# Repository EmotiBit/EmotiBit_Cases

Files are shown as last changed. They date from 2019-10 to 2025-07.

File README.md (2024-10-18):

## EmotiBit Cases

| EmotiBit Case | Preview | EmotiBit<br>Compatibility | Feather<br>Compatibility |
| --- | --- | --- | --- |
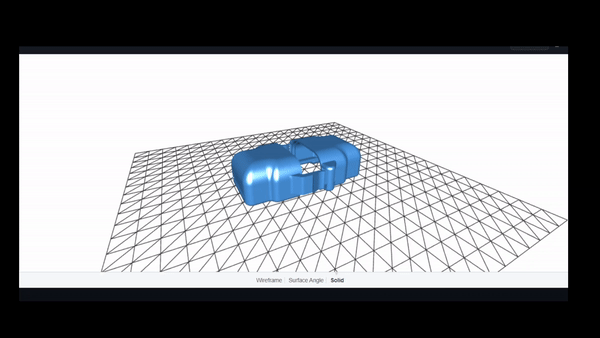
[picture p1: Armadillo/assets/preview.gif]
| [SwissArmyCase](./SwissArmyCase/) |  | <table><tr><th>EmotiBit<br>Version</th><th>Fit?</th></tr><tr><td>V01</td><td>Y</td></tr><tr><td>V02</td><td>Y</td></tr><tr><td>V03</td><td>Y</td></tr><tr><td>V04+</td><td>Y</td></tr></table> | <table><tr><th>Feather<br>Version</th><th>Fit?</th></tr><tr><td><a href=https://www.adafruit.com/product/2598>M0 WiFi<br>Regular Header</a></td><td>Y</td></tr><tr><td><a href=https://www.adafruit.com/product/3044>M0 WiFi<br>Stacking Header</a></td><td>Y</td></tr><tr><td><a href=https://www.adafruit.com/product/3591>HUZZAH32 <br>Regular Header</a></td><td>Y</td></tr><tr><td><a href=https://www.adafruit.com/product/3619>HUZZAH32 <br>Stacking Header</a></td><td>Y</td></tr></table> |
| [Armadillo](./Armadillo/) |  | <table><tr><th>EmotiBit<br>Version</th><th>Fit?</th></tr><tr><td>V01</td><td>Y</td></tr><tr><td>V02</td><td>Y</td></tr><tr><td>V03</td><td>Y</td></tr><tr><td>V04+</td><td>Y?</td></tr></table> | <table><tr><th>Feather<br>Version</th><th>Fit?</th></tr><tr><td><a href=https://www.adafruit.com/product/2598>M0 WiFi<br>Regular Header</a></td><td>Y</td></tr><tr><td><a href=https://www.adafruit.com/product/3044>M0 WiFi<br>Stacking Header</a></td><td>N</td></tr></table> |
| [NinjaCase](./NinjaCase/) |  | <table><tr><th>EmotiBit<br>Version</th><th>Fit?</th></tr><tr><td>V01</td><td>Y?</td></tr><tr><td>V02</td><td>Y?</td></tr><tr><td>V03</td><td>Y?</td></tr><tr><td>V04+</td><td>Y</td></tr></table> | <table><tr><th>Feather<br>Version</th><th>Fit?</th></tr><tr><td><a href=https://www.adafruit.com/product/2598>M0 WiFi<br>Regular Header</a></td><td>Y*</td></tr><tr><td><a href=https://www.adafruit.com/product/3044>M0 WiFi<br>Stacking Header</a></td><td>N</td></tr></table> |
## Want to Contribute to the EmotiBit Cases Repository?
See [CONTRIBUTING.md](./CONTRIBUTING.md)

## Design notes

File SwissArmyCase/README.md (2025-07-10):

## Description
- The case has been designed keeping in mind the design requirements for EmotiBit V4+ and extending compatibility with Adafruit Feather with stacking headers.
- The slider has been designed to provide easy access to toggle the hibernate (HIB) switch (available on EmotiBit V4+).

## Preview

### Case



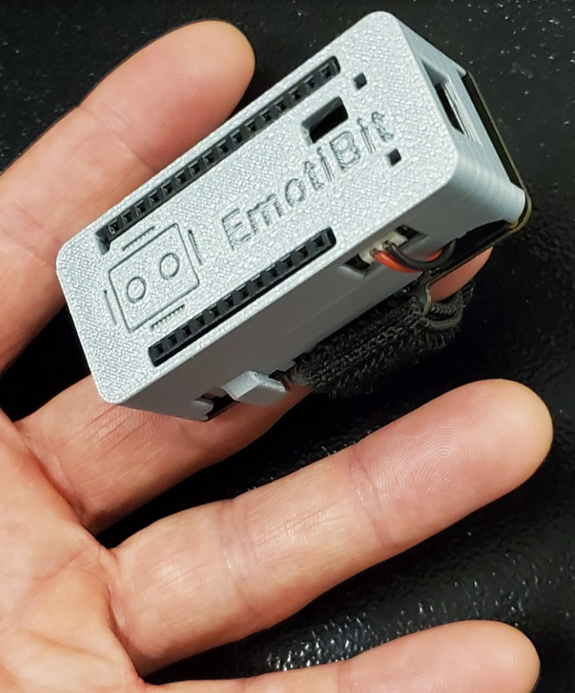
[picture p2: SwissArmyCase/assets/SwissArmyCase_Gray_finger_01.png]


### Slider
- The slider when correctly positioned inside the case, provides an easy and convinient way to toggle the hibernate (HIB)
switch. 
- The hibernate (HIB) switch can be toggled by by pushing the slider in from either direction. 

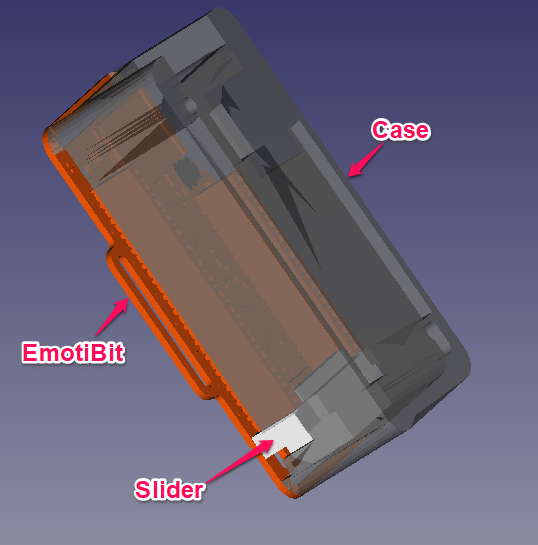
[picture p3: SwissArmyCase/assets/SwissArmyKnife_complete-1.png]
 

[ToDo: Add updated image]

## EmotiBit Compatibility
<!--- This table is written in minified html to permit scraping into a sub-table in the root EmotiBit_Cases/readme.md -->
<table><tr><th>EmotiBit<br>Version</th><th>Fit?</th></tr><tr><td>V01</td><td>Y</td></tr><tr><td>V02</td><td>Y</td></tr><tr><td>V03</td><td>Y</td></tr><tr><td>V04+</td><td>Y</td></tr></table>

## Feather Compatibility
<!--- This table is written in minified html to permit scraping into a sub-table in the root EmotiBit_Cases/readme.md -->
<table><tr><th>Feather<br>Version</th><th>Fit?</th></tr><tr><td><a href=https://www.adafruit.com/product/2598>M0 WiFi<br>Regular Header</a></td><td>Y</td></tr><tr><td><a href=https://www.adafruit.com/product/3044>M0 WiFi<br>Stacking Header</a></td><td>Y</td></tr><tr><td><a href=https://www.adafruit.com/product/3591>HUZZAH32 <br>Regular Header</a></td><td>Y</td></tr><tr><td><a href=https://www.adafruit.com/product/3619>HUZZAH32 <br>Stacking Header</a></td><td>Y</td></tr></table>

## Hardware Modifications
None required.

## 3D Printing
| Works? | Vendor/Printer | Material | Notes |
| :----: | --- | --- | --- |
| Y | [xometry](https://www.xometry.com/) | Selective Laser Sintering (SLS) Nylon 12 | Process: 3D Printing Technology: Selective Laser Sintering (SLS) Material: Nylon 12, Color: Black-Dyed Finish: Standard |

## Additional Hardware
None

## Assembly
- Stack the EmotiBit as demonstrated in the [documentation](https://github.com/EmotiBit/EmotiBit_Docs/blob/master/Getting_Started.md#stack-your-emotibit), but don't plug the battery into the Feather just yet.
- Place the slider between the EmotiBit and Feather such that the bottom notch on the slider fits over the hibernate (HIB) switch on EmotiBit.
- Fit the case over assembled EmotiBit+Feather (with the slider now sandwiched between the EmotiBit and Feather).
  - You will notice that the slider stands flush with the slots on the case.
  - Gently bring the case down and fasten the clips over the EmotiBit.
- Plug in the battery.

[ToDo: add images demonstrating assembly]

## Feature Accessibility
| Feature | Accessible? |
| --- | :----: |
| SD card | Y |
| EmotiBit Button | Y |
| USB connector | Y |
| EmotiBit LEDs visible | Y |
| Feather LEDs visible | Y |
| Short-edge EmotiBit strap slots | Y |
| Long-edge EmotiBit strap slots  | Y |
| Hibernate switch (with slider) | Y |
| Battery connector | Y |
| Battery removal/replacement | Case must be partially removed |
| Feather reset button | Requires spudger |
| Feather stacking header pins | Y |

## Known Limitations
None

## Credits
Designed by the EmotiBit team

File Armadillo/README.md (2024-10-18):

## Description
This case was designed for snowboarders to wear EmotiBit while performing tricks in a halfpipe. 

## Preview


## EmotiBit Compatibility
<!--- This table is written in minified html to permit scraping into a sub-table in the root EmotiBit_Cases/readme.md -->
<table><tr><th>EmotiBit<br>Version</th><th>Fit?</th></tr><tr><td>V01</td><td>Y</td></tr><tr><td>V02</td><td>Y</td></tr><tr><td>V03</td><td>Y</td></tr><tr><td>V04+</td><td>Y?</td></tr></table>

### EmotiBit Compatibility Notes
- EmotiBit V04/V05 just barely fits length-wise into this case with Shapeways PVP print. This case may not fit V04/V05 with other printers/plastic.

## Feather Compatibility
<!--- This table is written in minified html to permit scraping into a sub-table in the root EmotiBit_Cases/readme.md -->
<table><tr><th>Feather<br>Version</th><th>Fit?</th></tr><tr><td><a href=https://www.adafruit.com/product/2598>M0 WiFi<br>Regular Header</a></td><td>Y</td></tr><tr><td><a href=https://www.adafruit.com/product/3044>M0 WiFi<br>Stacking Header</a></td><td>N</td></tr></table>

## Hardware Modifications
None required.

## 3D Printing
| Works? | Vendor/Printer | Material | Notes |
| :----: | --- | --- | --- |
| Y | [shapeways](https://www.shapeways.com/) | Processed Versatile Plastic | Robust case for extreme conditions. |
| Y? | [shapeways](https://www.shapeways.com/) | Dark Gray PA12 Glass Beads | Somewhat fragile. Clips can break if not careful. |

## Additional Hardware
None

## Feature Accessibility
| Feature | Accessible? |
| --- | :----: |
| SD card | Case must be partially removed |
| EmotiBit Button | Case must be partially removed |
| USB connector | Case must be partially removed |
| EmotiBit LEDs visible | LEDs are somewhat visible through case material |
| Feather LEDs visible | LEDs are somewhat visible through case material |
| Short-edge EmotiBit strap slots | Y |
| Long-edge EmotiBit strap slots  | N |
| Hibernate switch | Case must be partially removed |
| Battery connector | Case must be partially removed |
| Battery removal/replacement | Case must be partially removed |
| Feather reset button | Case must be partially removed |
| Feather stacking header pins | N/A |

## Known Limitations
This case will work ONLY when using with a non-stacking Adafruit Feather (e.g. https://www.adafruit.com/product/2598), such as those shipped with EmotiBit Beta Units.



With a stacking-header Adafruit Feather (e.g. https://www.adafruit.com/product/3044) that is shipping with Kickstarter orders and preorders on http://shop.emotibit.com/ a slightly taller case design must be utilized.



## Credits
Designed by the Paquette Lab at the Université du Québec à Chicoutimi (UQAC)

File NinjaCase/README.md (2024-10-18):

## Description
This case requires removing the battery connector. It exposes only the side velcro band slots. Designed to print in flexible filament.

## Preview


## EmotiBit Compatibility
<!--- This table is written in minified html to permit scraping into a sub-table in the root EmotiBit_Cases/readme.md -->
<table><tr><th>EmotiBit<br>Version</th><th>Fit?</th></tr><tr><td>V01</td><td>Y?</td></tr><tr><td>V02</td><td>Y?</td></tr><tr><td>V03</td><td>Y?</td></tr><tr><td>V04+</td><td>Y</td></tr></table>

## Feather Compatibility
<!--- This table is written in minified html to permit scraping into a sub-table in the root EmotiBit_Cases/readme.md -->
<table><tr><th>Feather<br>Version</th><th>Fit?</th></tr><tr><td><a href=https://www.adafruit.com/product/2598>M0 WiFi<br>Regular Header</a></td><td>Y*</td></tr><tr><td><a href=https://www.adafruit.com/product/3044>M0 WiFi<br>Stacking Header</a></td><td>N</td></tr></table>

## Hardware Modifications
You must de-solder the battery connector on the Feather, and hard solder the battery wires to the Feather battery connector pads.

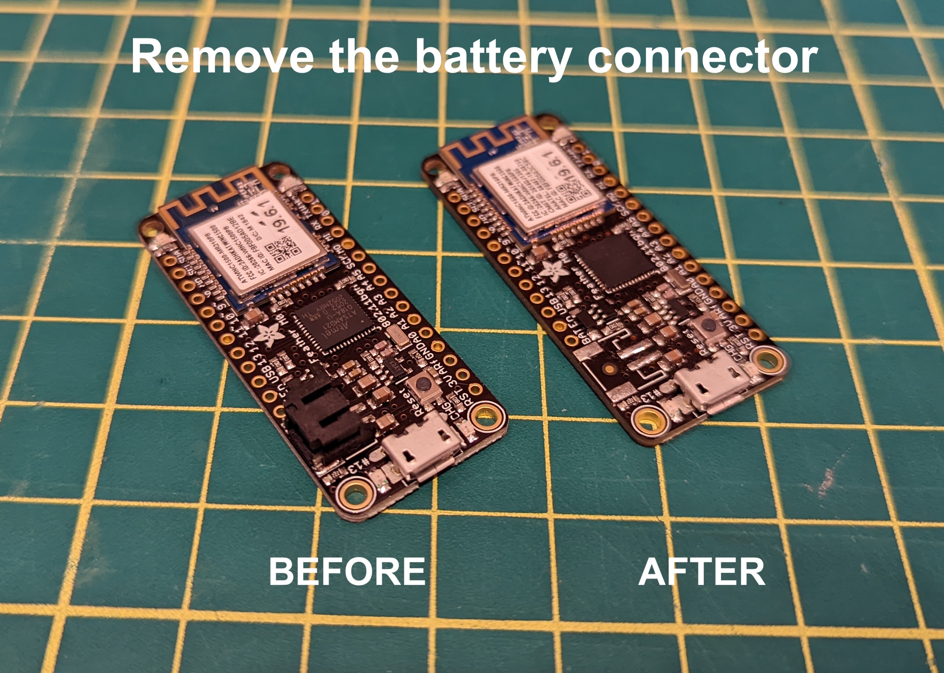
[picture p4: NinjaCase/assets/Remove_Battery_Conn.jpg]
Feather Battery connector


In order to protect the battery wires, it's best to route them through the Feather Mount Hole right next to the battery solder pads.

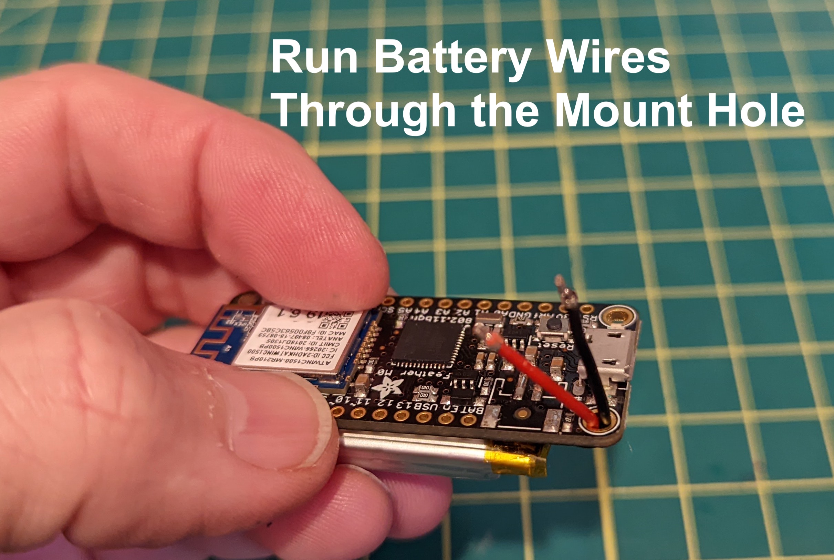
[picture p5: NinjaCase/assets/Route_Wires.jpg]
Route Wires


The black wire (GND) solders to the skinny pad closer to the USB port.
Red wire goes on the skinny pad further from the USB port.

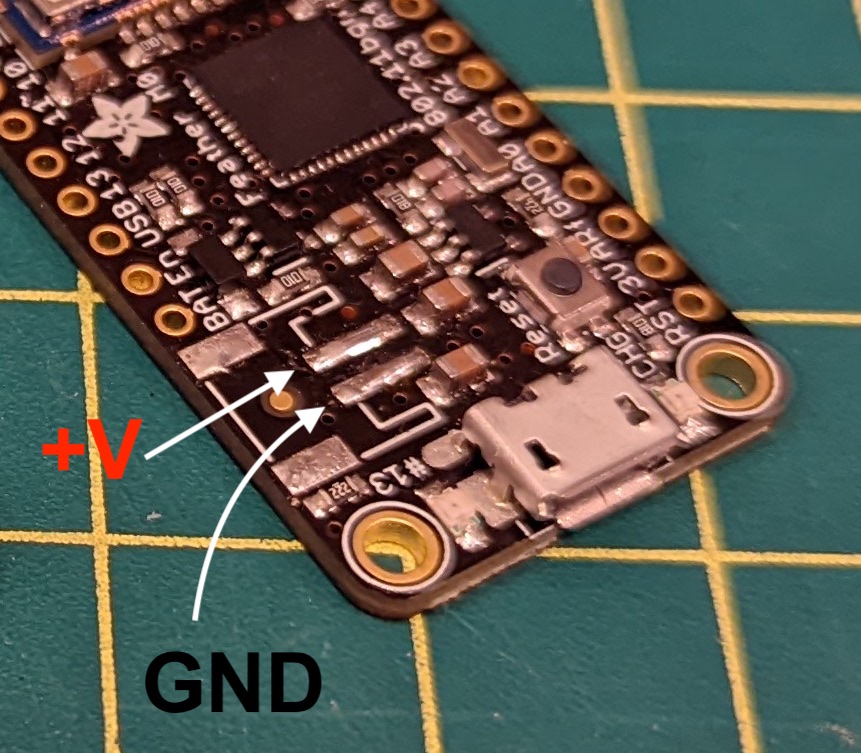
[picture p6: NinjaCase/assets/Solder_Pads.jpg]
Solder Pads


Install the Feather + Emotibit into the case by first sliding in the USB end. Then stretch the case around the opposite end of the Feather + Emotibit assembly. It's kind of like putting on a bike tire. Best to use a spudger or other plastic tool to stretch against the PCBs. 

## 3D Printing
| Works? | Vendor/Printer | Material | Notes |
| :----: | --- | --- | --- |
| Y | TAZ Mini 2 | NinjaTek Ninja Flex filament | 20% Infill. With Supports. Standard Resolution. |

## Additional Hardware
None

## Feature Accessibility
| Feature | Accessible? |
| --- | :----: |
| SD card | Y |
| EmotiBit Button | Y |
| USB connector | Y |
| EmotiBit LEDs visible | Y |
| Feather LEDs visible | N |
| Short-edge EmotiBit strap slots | N |
| Long-edge EmotiBit "side" strap slots  | Y |
| Hibernate switch | N |
| Battery connector | Removed |
| Battery removal/replacement | Soldered |
| Feather reset button | With paperclip |
| Feather stacking header pins | N |

## Known Limitations
Some caution should be exercised when inserting/removing EmotiBit. It's a tight fit and it can damage the EmotiBit strap slots if you aren't careful.

## Credits
Designed by the Joel Murphy @biomurph

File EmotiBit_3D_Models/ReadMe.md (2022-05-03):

3D models of different EmotiBit versions can be found in this directory.

After removing the SD card, the version information for each EmotiBit can be found written in white silkscreen lettering on the PCB.

[ToDo: Add image]

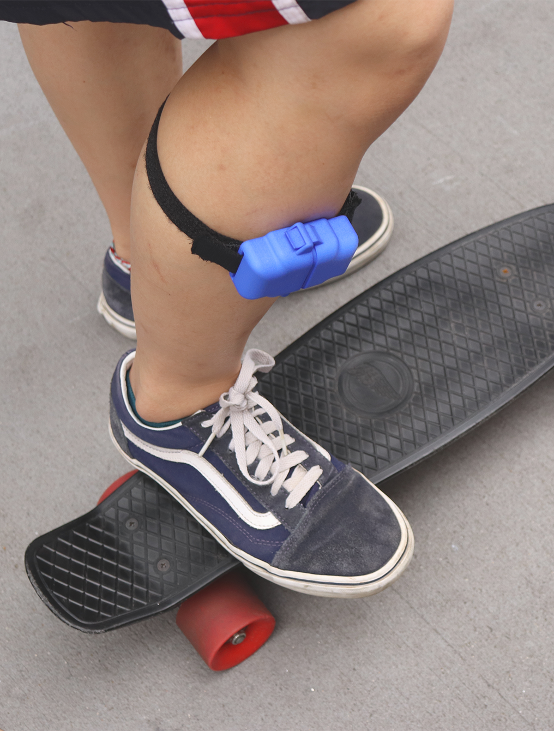
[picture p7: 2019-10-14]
Armadillo/skateboard5.png

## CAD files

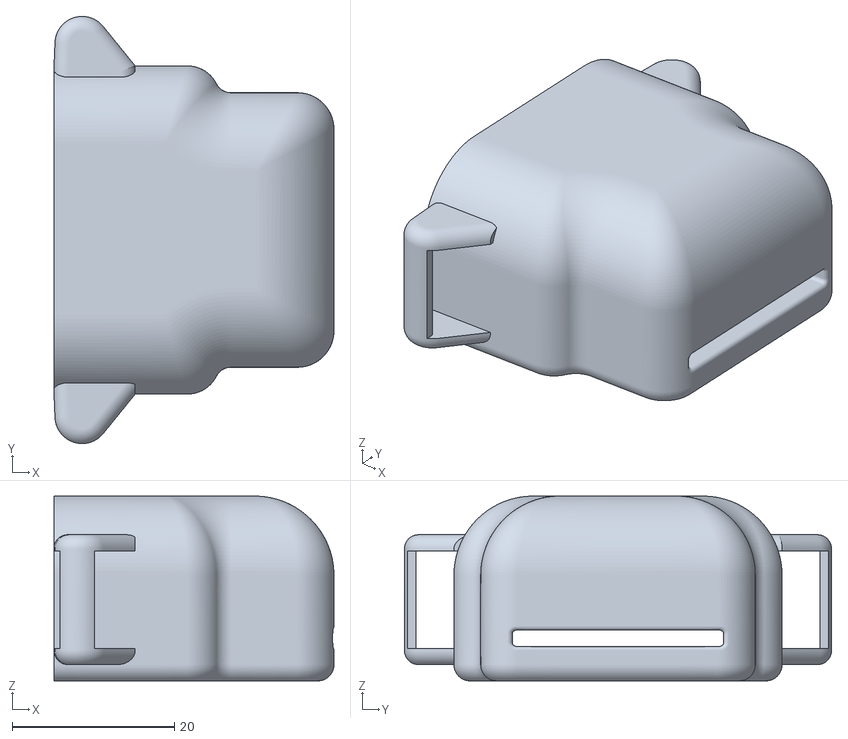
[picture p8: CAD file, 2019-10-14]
Armadillo/Armadillo-part1.stl
34.5 x 52.6 x 22.8

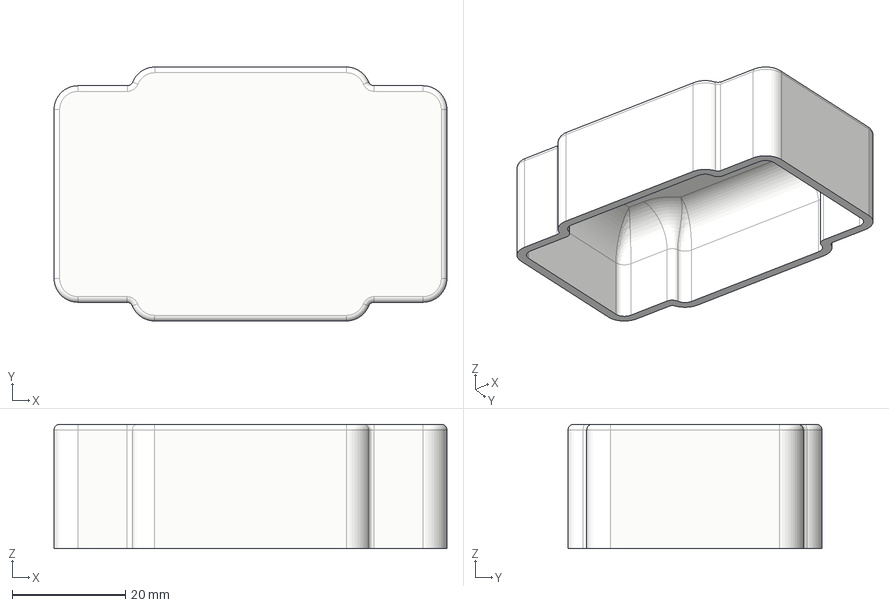
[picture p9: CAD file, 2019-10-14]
Armadillo/STEP files/Emotibit_moule.step
69.5 x 44.9 x 22.0 mm

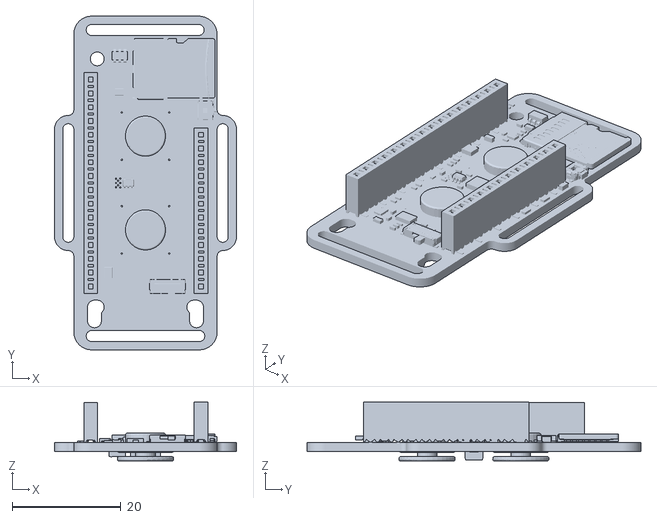
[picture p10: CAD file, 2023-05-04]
EmotiBit_3D_Models/V06/EmotiBit_V06.stl
33.5 x 61.5 x 10.9

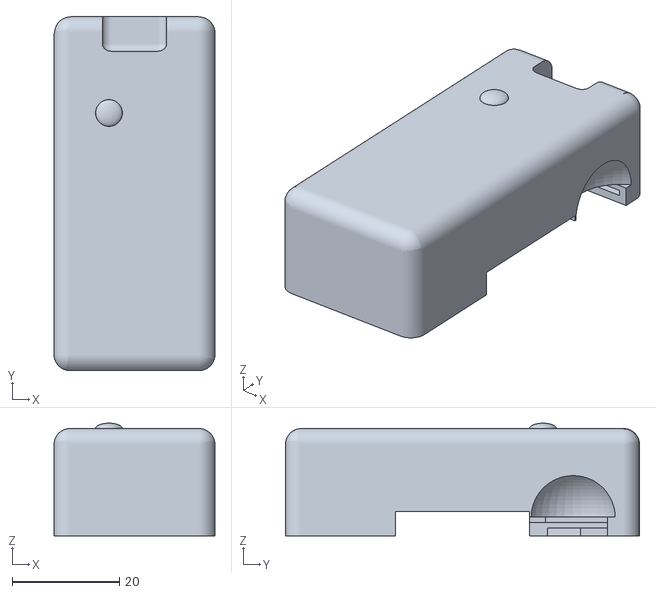
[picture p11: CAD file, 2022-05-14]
NinjaCase/NinjaCase.stl
30.0 x 66.0 x 21.0

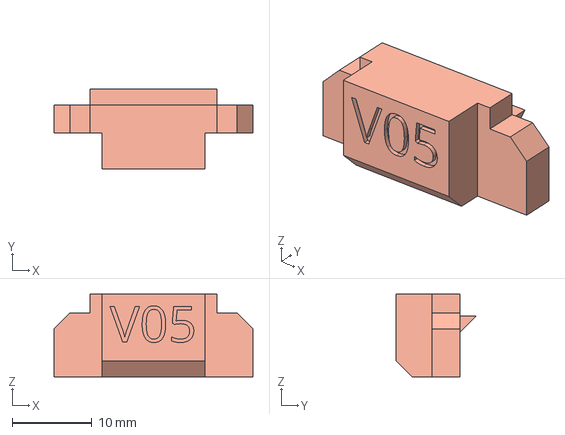
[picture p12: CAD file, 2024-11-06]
SwissArmyCase/SwissArmyCase_slider.step
24.9 x 10.0 x 10.3 mm

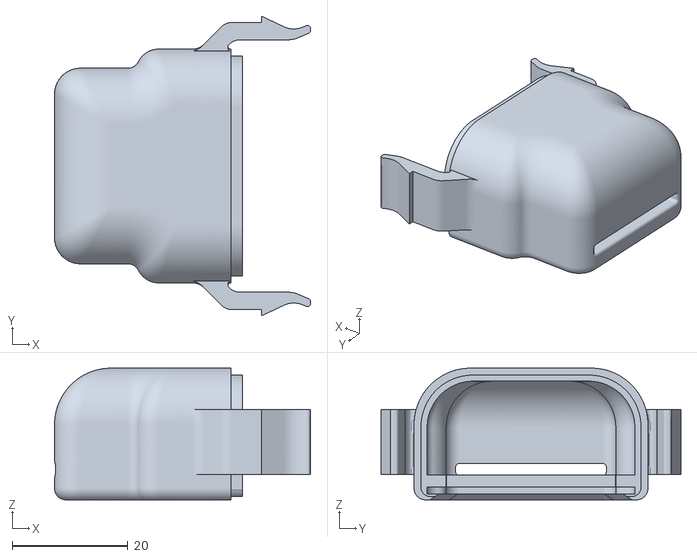
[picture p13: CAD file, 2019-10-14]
Armadillo/Armadillo-part2.stl
44.2 x 51.8 x 22.8

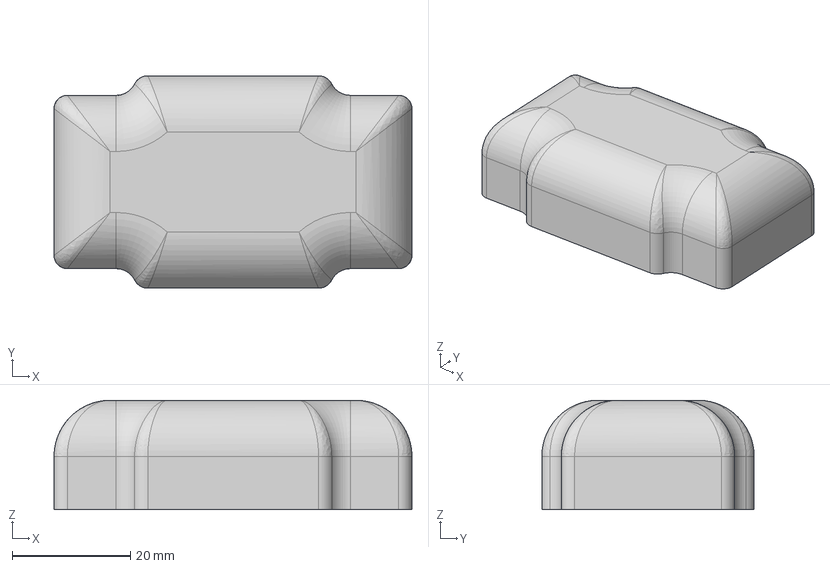
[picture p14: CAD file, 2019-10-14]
Armadillo/STEP files/Emotibit_contre_moule.step
60.5 x 35.9 x 18.5 mm

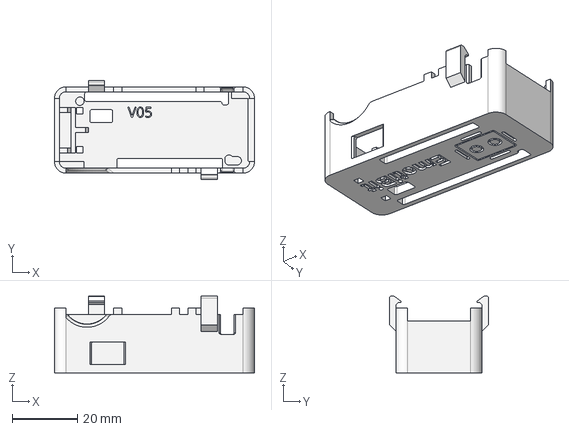
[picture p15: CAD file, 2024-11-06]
SwissArmyCase/SwissArmyCase_shell.step
61.5 x 30.5 x 23.6 mm

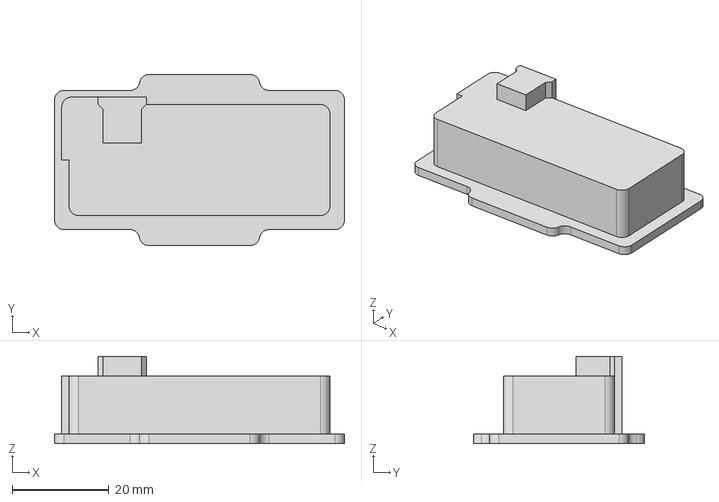
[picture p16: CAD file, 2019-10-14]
Armadillo/STEP files/Emotibit_pour_moule.step
60.0 x 35.4 x 18.0 mm

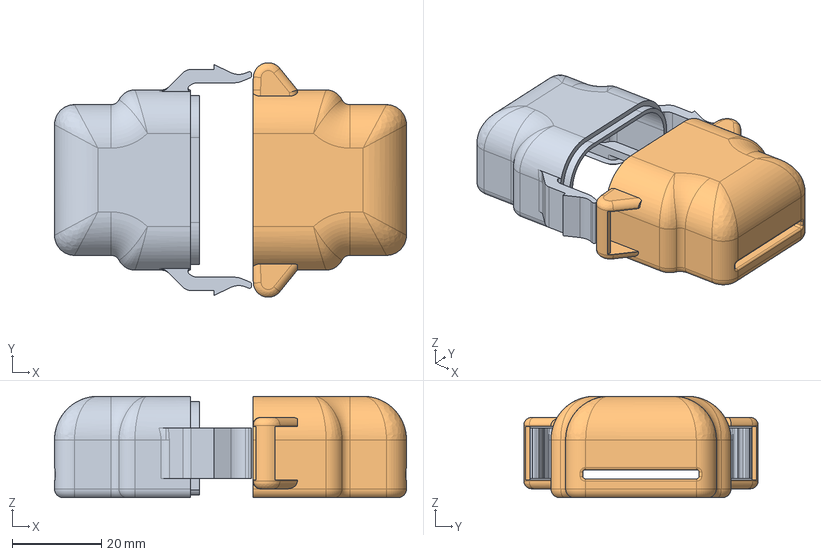
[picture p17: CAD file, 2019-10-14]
Armadillo/STEP files/Emotibit_case_lastest_20190208.step
78.9 x 52.6 x 22.8 mm

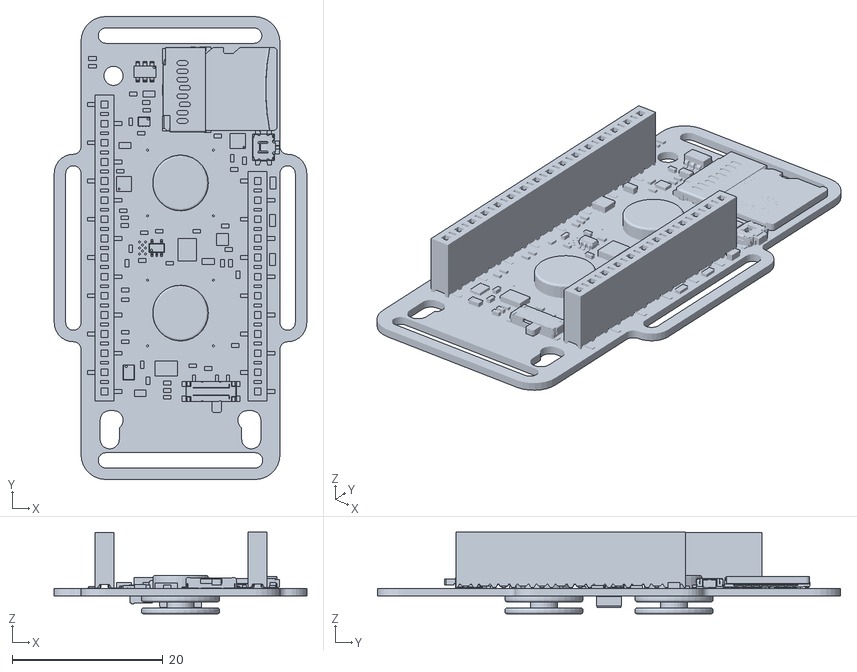
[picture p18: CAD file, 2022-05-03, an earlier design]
EmotiBit_3D_Models/V04/EmotiBit_V04.stl
33.5 x 61.5 x 10.9

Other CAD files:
Armadillo/Fusion360 source files/Emotibit_case_lastest_20190208.f3d
Armadillo/Fusion360 source files/Emotibit_contre_moule.f3d
Armadillo/Fusion360 source files/Emotibit_moule.f3d
Armadillo/Fusion360 source files/Emotibit_pour_moule.f3d
SwissArmyCase/SwissArmyCase_shell.stl
SwissArmyCase/SwissArmyCase_slider.stl

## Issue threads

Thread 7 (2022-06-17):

Add a chamfer to the swiss army case slider

nitin710, 2022-06-17:
- Adding the chamfer resolved possible situations where the case blocks slider movement because of difference in printer outputs

Closed 2022-06-21.

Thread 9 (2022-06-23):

Make the SwissArmyCase slider and screws thinner for the HUZZAH32

produceconsumerobot, 2022-06-23:

produceconsumerobot, 2024-10-21:
Screws no longer needed -- clips used instead

Closed 2024-10-21.

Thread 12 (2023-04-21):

SwissArmyCase: Consider if there's a way to make the reset button finger pushable

produceconsumerobot, 2023-04-21:

produceconsumerobot, 2024-10-21:
Not super easy fix. Spudger works ok.

Closed 2024-10-21.

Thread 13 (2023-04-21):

SwissArmyCase: Add case support feat to prevent bending emotibit PCB

produceconsumerobot, 2023-04-21:
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

Closed 2024-10-21.

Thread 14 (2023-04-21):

SwissArmyCase: Add clips onto case body to hold onto EmotiBit PCB

produceconsumerobot, 2023-04-21:
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
I'm imagining clips that sit kitty corner next to the side strap attachment to provide easier "one clip at a time" removal and prevent sliding when used with non-stacking header.
We may wish to make the notch in the clips support either 0.047in or 0.062in PCBs for forward compatibility.

Closed 2024-10-21.

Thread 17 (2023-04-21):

SwissArmyCase: Chamfer slider top outer corners to prevent catching on case

produceconsumerobot, 2023-04-21:
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

Closed 2024-10-21.

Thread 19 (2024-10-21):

SwissArmyCase: Make case supports on the long edge wider to span full distance between connector pads

produceconsumerobot, 2024-10-21:
Wider supports may help keep the case from sliding lengthwise because the supports would run into the connector pins and stop

produceconsumerobot, 2024-11-16:
I'm not sure this will help prevent sliding of the case

Closed 2024-11-16.

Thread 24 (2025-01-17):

Reset hole needs to fit 7.6mm wide spudger

produceconsumerobot, 2025-01-17:

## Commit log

2019-10-14 Added case design
    [Emotibit_case_lastest_20190208.f3d, Emotibit_case_lastest_20190208.step, Emotibit_case_lastest_20190208_part1.stl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]
2022-03-07 First commit with STL and readme
    [Emotibit_Case_NinjaFlex.stl]
2022-04-12 Adding EmotiBit V4 3D files and case files
    [EmotiBitCase.step, EmotiBitCase.stl, EmotiBit_V4.stl]
2022-04-21 reorganized directories
    [EmotiBitCase.step, EmotiBitCase.stl, EmotiBitCase_0-A-part1.stl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]
2022-05-03 reorg attempt #1
    [EmotiBit_V4.stl]
2022-05-03 Fixed 3D printing table
2022-05-03 renamed to V04
    [EmotiBit_V04.stl]
2022-05-03 renamed cases with mnemonically salient names
    [Armadillo-A-part1.stl, Armadillo-A-part2.stl, Emotibit_case_lastest_20190208.f3d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]
2022-05-03 3D Printing
2022-05-14 Renamed & conformed NinjaCase readme
    [NinjaCase.stl]
2022-05-14 Renamed Armadillo stl
    [Armadillo-part1.stl, Armadillo-part2.stl]
2022-05-14 Renamed SwissArmyCase
    [SwissArmyCase.step, SwissArmyCase.stl]
2022-05-19 updated read me with hibernate toggle switch. added new assets and new 3D files
    [SwissArmyCase_shell-v01.step, SwissArmyCase_shell-v01.stl, SwissArmyCase_switch-v01.step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]
2022-05-19 renamed switch to slider. documentation change
    [SwissArmyCase_slider-v01.step, SwissArmyCase_slider-v01.stl]
2022-05-20 conforming to naming swissArmyCase
    [SwissArmyCase_shell.step, SwissArmyCase_shell.stl, SwissArmyCase_slider.step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]
2022-06-17 Added hamfer to the swiss army case slider.
    [SwissArmyCase_slider.step, SwissArmyCase_slider.stl]
2023-05-04 adding 3D models for EmotiBit V5
    [EmotiBit_V05.stl]
2024-10-16 Added V06 model
    [EmotiBit_V06.stl]
2024-10-16 updated step and stl files
    [SwissArmyCase_shell.step, SwissArmyCase_shell.stl, SwissArmyCase_slider.step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]
2024-10-17 Assembly instructions update
2024-11-06 Thicker wall to hold slider in place
    [SwissArmyCase_shell.step, SwissArmyCase_shell.stl, SwissArmyCase_slider.step]
2025-07-10 Updated case on finger pic
